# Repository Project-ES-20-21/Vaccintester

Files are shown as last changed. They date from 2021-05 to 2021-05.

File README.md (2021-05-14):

# RainbowSyringe
Dit is de uitleg horende bij de vaccintester uit de escape room.

## Inhoud

- [Algemene uitleg](#algemene-uitleg)
- [Flowcharts](#flowcharts)
- [Implementatie](#implementatie)
- [Budget](#budget)
- [Risico's](#risicos)
- [Gantt chart](#gantt-chart)

## Algemene uitleg

Door het oplossen van de 5G-puzzel, wordt er een RFID kaart verkregen. Die kaart kan gebruikt worden om de uiteindelijke kleurensequentie voor de vaccintester te vinden. In de deur van een kast zit op een bepaalde plaats een NFC reader. De spelers moeten dan met de kaart op zoek gaan naar de kast en uitzoeken waar in de deur de NFC reader zit. Door de kaart dan te scannen worden er witte leds in de kast geactiveerd. Boven elke witte led bevindt zich een gekleurde vloeistof in een proefbuis. De houders voor de proefbuis kunnen gebruikt worden om de witte leds weg te steken. De leds gaan in een bepaalde volgorde oplichten, zodat er een sequentie gevonden kan worden van 7 kleuren die na elkaar oplichten. Om die kleurensequentie in te geven wordt er gebruik gemaakt van drie knoppen die verspreid zijn in de ruimte. Bij elke knop hoort een kastje, hierin kan een voorwerp met een primaire kleur gestoken worden. Om de kleuren te vormen worden de knoppen dan ingedrukt, de kleur van het voorwerp wordt gescand. Om alle spelers te laten meedoen moeten de knoppen om de kleuren te vormen binnen een bepaald interval ingedrukt worden. Zo wordt geel gevormd door groen, rood en zwart moeten groen, rood en zwart dus ongeveer op hetzelfde moment ingedrukt worden. Die knoppen zorgen er dan voor dat de bijhorende ledstrip die zich in een spuit bevindt oplicht. Wanneer de juiste kleur verkregen is wordt er gesprongen naar de volgende kleur in de sequentie en herhaalt het vorige zich. Wanneer de laatste kleur juist is, wordt een random getal gegenereerd dat een digit van de te zoeken code is. Deze wordt doorgestuurd naar de centrale eenheid en ook getoond aan de deelnemers door het aantal proefbuizen die oplichten binnen de kast.

Om dit alles te kunnen uitvoeren wordt er gebruik gemaakt van twee ESP32's, die met elkaar kunnen communiceren via een ESPnow-connectie. Wanneer de juiste RFID gescand wordt, wordt er een signaal verzonden van de ESP32 die verbonden is met de NFC-reader naar de ESP32 die verbonden is met de kleursensoren, de drukknoppen en de leds binnen de spuit en in de kast. Dat signaal zal ervoor zorgen dat de kleursensoren, de leds binnen de spuit en in de kast en de drukknoppen geactiveerd worden.

Daarnaast zal de laatst besproken ESP via het wifi-netwerk geconnecteerd zijn met de broker. Op die manier kan er uiteindelijk een digit van de code die ingevoerd moet worden bij alohomara doorgestuurd worden naar de centrale eenheid of broker.

## Flowcharts
### Vaccintester
Flowchart_vaccintester
### RFID
Flowchart_RFID
### Buttons
Flowchart_buttons
### Centrale ESP32
Flowchart_centralESP32

## Implementatie

De positie van deze puzzel binnen het lokaal maakt in principe niet zo veel uit. Er moet wel voor gezorgd worden dat de knoppen minstens 1,5 meter van elkaar gescheiden zijn zodat telkens aan de voorwaarde van de "T'is beter op anderhalve meter"-puzzel voldaan is. Daarnaast gaat de spuit aan een muur moeten hangen zodat alles op een correcte manier aangesloten kan worden.

## Budget

| Artikel | Aantal | Kostprijs | Totaal  |
|---|---|---|---|
| Kleurensensor | 1 | 4.00 € | 4.00 €  |
| Esp32 | 2 | 5.79 € | 11.58 € |
| NRF24L01+ 2.4GHz wireless transceiver module | 3 | 1.95 € | 5.85 €  |
| Witte led | 7 | 0.42 € | 2.94 €  |
| Kleurenledstrip 1m | 1 | 10.00 € | 10.00 € |
| NFC reader | 1 | 5.00 € | 5.00 €  |
| Weerstanden | 7 | x | x |
| RobotDynUNO R3 | 1 | 11.00 € | 11.00 € |
| | | | |
| Hebben we reeds | | | 50.37 € |
| | | | |
| Drukknoppen | 3 | 2.00 € | 6.00 €  |
| Adapters | 5 | x | x |
| PCBway | 1 | 5.00 € | 5.00 €  |
| Kleurensensor | 2 | 4.00 € | 8.00 €  |
| RobotDynUNO R3 | 2 | 11.00 € | 22.00 € |
| | | | |
| Nog aan te kopen | | | 41.00 € |
| | | | |
| Totaal budget | | | 91.37 € |
| | | | |
## Risico's

- Wanneer de 5G-puzzle niet werkt, kan de nodige RFID kaart niet verkregen worden. Dit kan opgelost worden door een tweede kaart te gebruiken die ook gebruikt kan worden om onze puzzel te starten. Deze kaart kan ergens verstopt worden binnen de kamer. De positie van die kaart kan dan via een raadsel achterhaald worden.

- Wanneer de RFID reader en de receiver niet geconnecteerd zijn, kan de puzzel niet volledig gestart worden. Dit kan eventueel opgelost worden door Alohomora een signaal te laten versturen naar de tweede ESP32. 

- De kleursensor kan soms bij de eerste meting een fout resultaat geven. Dit kan opgelost worden door bijvoorbeeld tien metingen na elkaar te doen en het gemiddelde te nemen van de verschillende waarden.

- De kleursensor kan foute resultaten geven door reflectie. Er moet dus gebruik gemaakt worden van een buis die mat is, waardoor de resultaten geen invloed van reflectie zullen hebben.

## Gantt chart

Via volgende link gaat u naar onze Gantt chart horende bij dit project: 
[Gantt vaccintester (ClickUp)](https://share.clickup.com/g/h/4dne7-50/c3532202026c060)

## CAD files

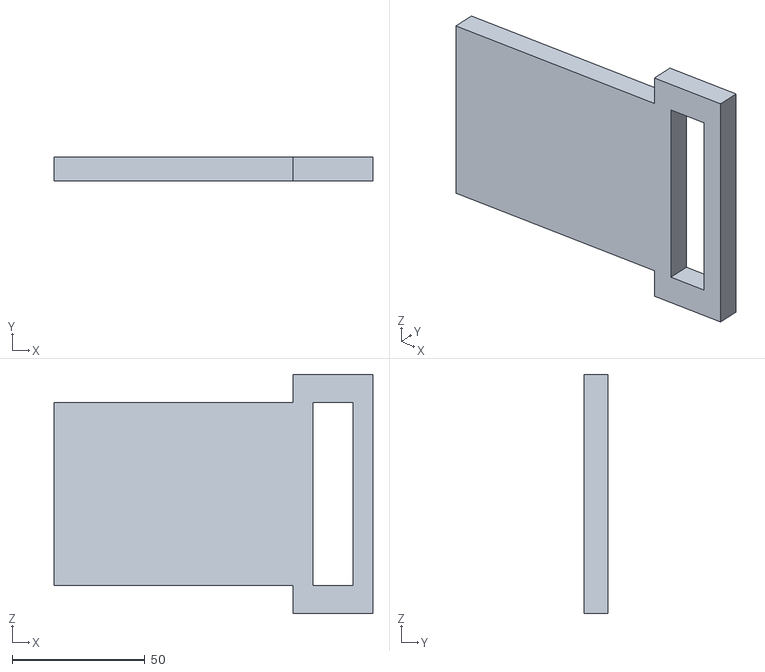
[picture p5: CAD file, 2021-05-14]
Kleur2.STL
120.0 x 9.00 x 90.0

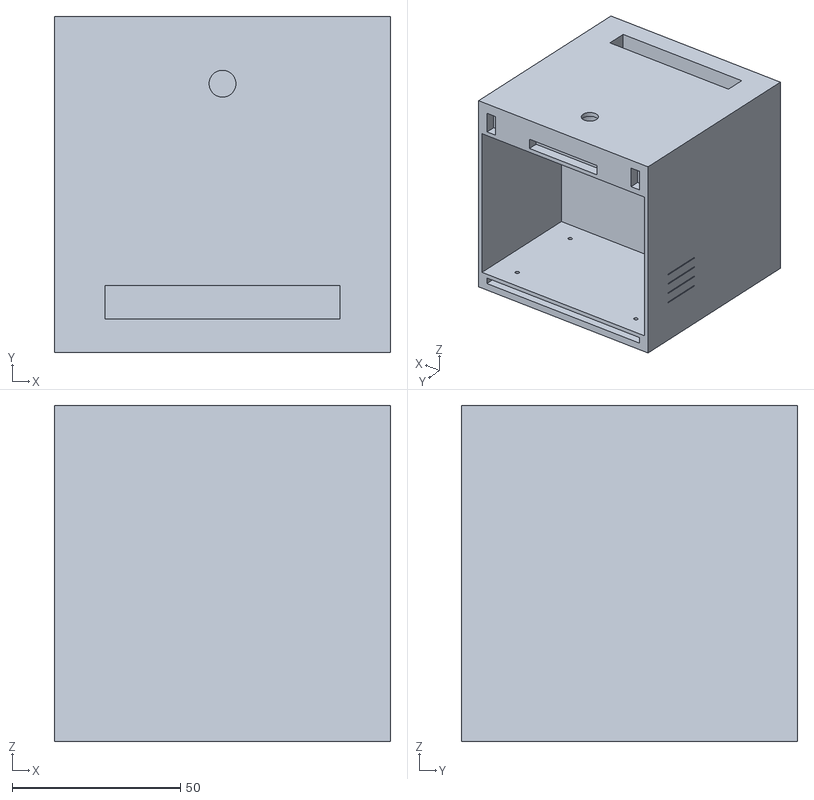
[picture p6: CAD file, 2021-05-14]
VaccintesterButtonF.STL
100.0 x 100.0 x 100.0

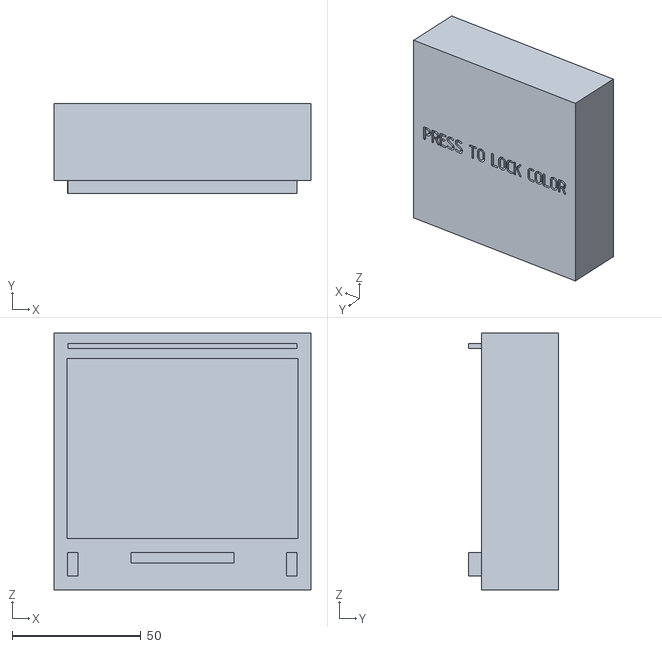
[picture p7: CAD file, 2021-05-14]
DekselButton.STL
100.0 x 35.0 x 100.0

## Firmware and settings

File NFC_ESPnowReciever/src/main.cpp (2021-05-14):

#include <Arduino.h>

#include <esp_now.h>
#include <WiFi.h>
#include "PubSubClient.h"
#include "Wire.h"
#include "SPI.h"
#include "Adafruit_SPIDevice.h"
#include "ESPAsyncWebServer.h"
#include <Arduino_JSON.h>
using namespace std;

#include <SPI.h>

//Mqtt constants
#define SSIDA "NETGEAR68"
#define PWD "excitedtuba713"
#define MQTT_SERVER "192.168.1.2" // could change if the setup is moved
#define MQTT_PORT 1883

WiFiClient espClient;
PubSubClient client(espClient);

unsigned long myPrevMillis;

void myDelay(int del)
{
  myPrevMillis = millis();
  while (millis() - myPrevMillis <= del)
  {
    client.loop();
  }
}

/////////////////////////////////////////////////////////////////////////////////////////////////////////////////////////////////////////
/////////////////////////////////////////////////////// SETUP LEDSTRIP //////////////////////////////////////////////////////////////////
/////////////////////////////////////////////////////////////////////////////////////////////////////////////////////////////////////////

#define red 26
#define green 27
#define blue 25

#define inPin 12

// setting PWM properties
const int freq = 5000;
const int redChannel = 0;
const int greenChannel = 1;
const int blueChannel = 2;
const int resolution = 8; //Resolution 8, 10, 12, 15

//=======================================================================
//                    Power on setup
//=======================================================================
void setupLed()
{

  pinMode(red, OUTPUT);
  pinMode(green, OUTPUT);
  pinMode(blue, OUTPUT);

  // configure LED PWM functionalitites
  ledcSetup(redChannel, freq, resolution);
  ledcSetup(greenChannel, freq, resolution);
  ledcSetup(blueChannel, freq, resolution);

  // attach the channel to the GPIO2 to be controlled
  ledcAttachPin(red, redChannel);
  ledcAttachPin(green, greenChannel);
  ledcAttachPin(blue, blueChannel);
}

void RGB_color(int red_light_value, int green_light_value, int blue_light_value)
{
  ledcWrite(redChannel, red_light_value);
  ledcWrite(greenChannel, green_light_value);
  ledcWrite(blueChannel, blue_light_value);
}

//int teller;
int redFrequency = 0;
int greenFrequency = 0;
int blueFrequency = 0;
int kleur = 6;

/*
  green = 0
  red = 1
  blue = 2
  yellow = 3
  purple = 4
  cyan = 5
  black = 6
*/

//Met behulp van de ontvangen kleuren de gemaakt kleur bepalen
int colorMaker(int mColor1, int mColor2)
{
  
  //groen
  if(((mColor1 == 0 || mColor2 == 0) && (mColor1 == 6 || mColor2 == 6)) || (mColor1 == 2 && mColor2 == 2)) {
      kleur=0;
      RGB_color(255, 0, 255);
    }
  //rood
  if(((mColor1 == 1 || mColor2 == 1) && (mColor1 ==6 || mColor2 ==6))|| (mColor1 == 1 && mColor2 == 1)) {
      kleur=1;
      RGB_color(0,255, 255);
    }
  //blauw
  if(((mColor1 == 2 || mColor2 == 2) && (mColor1 == 6 || mColor2 == 6)) || (mColor1 == 2 && mColor2 == 2)) {
      kleur=2;
      RGB_color(255, 255, 0);
    }
  //geel
  if((mColor1 == 0 || mColor2 == 0) && (mColor1 == 1 || mColor2 == 1)){
      kleur=3;
      RGB_color(0, 0, 255);
    }
  //paars
  if((mColor1 == 1|| mColor2 == 1) && (mColor1 == 2|| mColor2 == 2)){
      kleur=4;
      RGB_color(0, 255,0);
    }
  //cyaan
  if((mColor1 == 0|| mColor2 == 0) && (mColor1 == 2|| mColor2 == 2)){
      kleur=5;
      RGB_color(255, 0, 0);
    }
  if((mColor1 == 6)&&(mColor2 == 6)){
      kleur=6;
      RGB_color(0,0,0);
  }/*
  if (mColor1 == 0)
  {
    kleur = 0;
    RGB_color(255, 0, 255);
  }
  if (mColor1 == 1)
  {
    kleur = 1;
    RGB_color(0, 255, 255);
  }
  if (mColor1 == 2)
  {
    kleur = 2;
    RGB_color(255, 255, 0);
  }*/
  return kleur;
}

/////////////////////////////////////////////////////////////////////////////////////////////////////////////////////////////////////////
//////////////////////////////////////////////////////////// SETUP MQTT /////////////////////////////////////////////////////////////////
/////////////////////////////////////////////////////////////////////////////////////////////////////////////////////////////////////////

int sequence[7];

int reset = 0;
int pauze = 0;
int digitCode;
int color1;
int color2;
String sequentiestring;

void callback(char *topic, byte *message, unsigned int length);

void setup_wifi()
{
  myDelay(10);
  Serial.println("Connecting to WiFi..");

  WiFi.begin(SSIDA, PWD);

  while (WiFi.status() != WL_CONNECTED)
  {
    myDelay(500);
    Serial.print(".");
  }

  Serial.println("");
  Serial.println("WiFi connected");
  Serial.println("IP address: ");
  Serial.println(WiFi.localIP());
}

int pauzeFitness=0;
int pauzeOntsmet=0;

void callback(char *topic, byte *message, unsigned int length)
{
  Serial.print("Message arrived on topic: ");
  Serial.print(topic);
  Serial.print(". Message: ");
  String messageTemp;

  for (int i = 0; i < length; i++)
  {
    Serial.print((char)message[i]);
    messageTemp += (char)message[i];
  }
  Serial.println();

  // Feel free to add more if statements to control more GPIOs with MQTT

  // If a message is received on the topic esp32/output, you check if the message is either "on" or "off".
  // Changes the output state according to the message
  if (String(topic) == "esp32/vaccin/control")
  {
    //0 -- Reset
    if (messageTemp == "0")
    {
      for (int i = 0; i < 10; i++)
    {
      RGB_color(0, 255, 0);
      myDelay(200);
      RGB_color(255, 255, 255);
      myDelay(200);
    }
      ESP.restart();
      //reset = true;
    }
    //1 -- Pause ontsmetting
    if (messageTemp == "1")
    {
      pauzeOntsmet=1;
    }
    //2 -- Continue ontsmetting
    if (messageTemp == "2")
    {
      pauzeOntsmet=0;
    }
    //3 -- Pause fitness
    if (messageTemp == "3")
    {
      pauzeFitness=1;
    }
    //4 -- Continue ontsmetting
    if (messageTemp == "4")
    {
      pauzeOntsmet=0;
    }
  }

  if (String(topic) == "esp32/vaccin/button1")
  {
    Serial.println("Button1");
    color1 = messageTemp.toInt();
  }

  if (String(topic) == "esp32/vaccin/button2")
  {
    Serial.println("Button2");
    color2 = messageTemp.toInt();
  }

  if (String(topic) == "esp32/vaccin/kast")
  {
    Serial.println("Kast");
    sequentiestring = messageTemp;
    Serial.println(sequentiestring);
    sequence[0] = sequentiestring.substring(0, 1).toInt();
    sequence[1] = sequentiestring.substring(1, 2).toInt();
    sequence[2] = sequentiestring.substring(2, 3).toInt();
    sequence[3] = sequentiestring.substring(3, 4).toInt();
    sequence[4] = sequentiestring.substring(4, 5).toInt();
    sequence[5] = sequentiestring.substring(5, 6).toInt();
    sequence[6] = sequentiestring.substring(6, 7).toInt();

    for (int i = 0; i < 7; i++)
    {
      Serial.println(sequence[i]);
    }
  }
  if (String(topic) == "esp32/vaccin/number")
  {
    Serial.println(messageTemp);
  }
}

// function to establish MQTT connection
void reconnect()
{
  myDelay(10);
  // Loop until we're reconnected
  while (!client.connected())
  {
    Serial.print("Attempting MQTT connection...");
    // Attempt to connect
    if (client.connect("ESP32vaccin"))
    {
      Serial.println("connected");

      // ... and resubscribe
      client.subscribe("esp32/vaccin/control");
      client.subscribe("esp32/vaccin/number");
      client.subscribe("esp32/vaccin/button1");
      client.subscribe("esp32/vaccin/button2");
      client.subscribe("esp32/vaccin/kast");
    }
    else
    {
      Serial.print("failed, rc=");
      Serial.print(client.state());
      Serial.println(" try again in 5 seconds");
      myDelay(5000);
    }
  }
}

/////////////////////////////////////////////////////////////////////////////////////////////////////////////////////////////////////////
//////////////////////////////////////////////////////////// SETUP //////////////////////////////////////////////////////////////////////
/////////////////////////////////////////////////////////////////////////////////////////////////////////////////////////////////////////

void setup()
{
  //Initialize Serial Monitor
  Serial.begin(115200);

  setup_wifi();
  client.setServer(MQTT_SERVER, MQTT_PORT);
  client.setCallback(callback);

  //Set device as a Wi-Fi Station
  WiFi.mode(WIFI_STA);

  setupLed();
}

int val = 0;
int mixedColor;
int correct = 0;
int check = 0;

/////////////////////////////////////////////////////////////////////////////////////////////////////////////////////////////////////////
//////////////////////////////////////////////////////////// LOOP  //////////////////////////////////////////////////////////////////////
/////////////////////////////////////////////////////////////////////////////////////////////////////////////////////////////////////////

void loop()
{
  if (!client.connected())
  {
    reconnect();
  }
  client.loop();

  val = digitalRead(inPin); // read input value
  if ((val == HIGH) && (correct < 7) && (pauzeOntsmet == 0) && (pauzeFitness==0))
  {
    Serial.println("push");
    kleur = colorMaker(color2, color1);
    myDelay(1000);
    if (kleur != sequence[correct])
    {
      correct = 0;
      Serial.println(sequence[correct]);
      Serial.println("fout");
      for (int i = 0; i < 3; i++)
      {
        RGB_color(0, 255, 255); //rood laten pinken
        myDelay(350);
        RGB_color(255, 255, 255);
        myDelay(350);
      }
      colorMaker(color2, color1);
    }

    else if (kleur == sequence[correct])
    {
      Serial.println("Juist");
      correct++;
      Serial.println(sequence[correct]);
      for (int i = 0; i < 3; i++)
      {
        RGB_color(255, 0, 255); //groen laten pinken
        myDelay(350);
        RGB_color(255, 255, 255);
        myDelay(350);
      }
      colorMaker(color2, color1);
    }
  }

  if ((correct == 7) && (check == 0))
  {
    //random getal aanmaken
    srand(time(NULL));
    digitCode = rand() % 10;
    Serial.println(digitCode);

    String number = (String)digitCode;
    const char *alohomora = number.c_str();
    client.publish("esp32/vaccin/number", alohomora);
    Serial.println("Alohomora sent");

    //dat getal sturen naar de centrale
    //tonen op de ledstrip door aantal keer te laten pinken in wit
    for (int j = 0; j < 15; j++)
    { //15 keer het juiste getal laten zien afgewisseld met rood pinken
      for (int i = 0; i < digitCode; i++)
      {
        RGB_color(0, 0, 0);
        myDelay(350);
        RGB_color(255, 255, 255);
        myDelay(350);
      }
      for (int i = 0; i < digitCode; i++)
      {
        RGB_color(255, 255, 0);
        myDelay(350);
        RGB_color(255, 255, 255);
        myDelay(350);
      }
    }
    check = 1;
  }
}

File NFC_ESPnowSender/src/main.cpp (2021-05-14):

#include <Arduino.h>
#include <Wire.h>
#include <SPI.h>
#include <Adafruit_PN532.h>

#include <esp_now.h>
#include <esp_wifi.h>
#include <WiFi.h>
#include <Adafruit_Sensor.h>
#include <DHT.h>

#include <bits/stdc++.h>
#include <vector>
#include <algorithm>

using namespace std;

#include "PubSubClient.h"
#include "Wire.h"
#include "SPI.h"

//Mqtt constants
#define SSIDA "NETGEAR68"
#define PWD "excitedtuba713"
#define MQTT_SERVER "192.168.1.2" // could change if the setup is moved
#define MQTT_PORT 1883

WiFiClient espClient;
PubSubClient client(espClient);

unsigned long myPrevMillis;

void myDelay(int del)
{
  myPrevMillis = millis();
  while (millis() - myPrevMillis <= del)
  {
    client.loop();
  }
}

/////////////////////////////////////////////////////////////////////////////////////////////////////////////////////////////////////////
///////////////////////////////////////////////////////// SETUP NFC /////////////////////////////////////////////////////////////////////
/////////////////////////////////////////////////////////////////////////////////////////////////////////////////////////////////////////

static void startListeningToNFC();
static String handleCardDetected();

// Pins used for I2C IRQ
#define PN532_IRQ 4
#define PN532_RESET 5

//Pinnen leds
int red_color = 25;
int blue_color = 26;
int green_color = 27;
int yellow_color = 32;
int purple_color = 33;
int cyan_color = 14;

void setupPins()
{
  //Setup voor aansturen leds
  pinMode(blue_color, OUTPUT);
  pinMode(red_color, OUTPUT);
  pinMode(green_color, OUTPUT);
  pinMode(cyan_color, OUTPUT);
  pinMode(purple_color, OUTPUT);
  pinMode(yellow_color, OUTPUT);
}

const int DELAY_BETWEEN_CARDS = 500;
long timeLastCardRead = 0;
boolean readerDisabled = false;
int irqCurr;
int irqPrev;

//black Peter
string valid_tags = "0X04 0X9C 0X6E 0X6A 0X99 0X5B 0X80";

string reset_tags = "0X83 0X63 0XB3 0X03 0X00 0X00 0X00";

String hexToString(uint8_t *cardid);
boolean control(string kaart);

// This example uses the IRQ line, which is available when in I2C mode.
Adafruit_PN532 nfc(PN532_IRQ, PN532_RESET);

void startListeningToNFC()
{
  // Reset our IRQ indicators
  irqPrev = irqCurr = HIGH;

  Serial.println("Present an ISO14443A Card ...");
  nfc.startPassiveTargetIDDetection(PN532_MIFARE_ISO14443A);
}

String handleCardDetected()
{
  uint8_t success = false;
  uint8_t uid[] = {0, 0, 0, 0, 0, 0, 0}; // Buffer to store the returned UID
  uint8_t uidLength;                     // Length of the UID (4 or 7 bytes depending on ISO14443A card type)

  // read the NFC tag's info
  success = nfc.readDetectedPassiveTargetID(uid, &uidLength);
  Serial.println(success ? "Read successful" : "Read failed (not a card?)");

  if (success)
  {
    timeLastCardRead = millis();
  }

  // The reader will be enabled again after DELAY_BETWEEN_CARDS ms will pass.
  readerDisabled = true;
  return hexToString(uid);
}

String hexToString(uint8_t *cardid)
{

  int length = 7; //zonder +3 worden slechts 4 bytes genomen -> moet opgelost worden
  stringstream ss;
  for (int i = 0; i < length - 1; i++)
  {
    ss << "0x";
    if ((int)cardid[i] <= 15)
    {
      ss << "0";
    }
    ss << hex << (int)cardid[i];
    ss << " ";
  }
  ss << "0x";
  if ((int)cardid[length - 1] <= 15)
  {
    ss << "0";
  }
  ss << hex << (int)cardid[length - 1];
  string mystrC = ss.str();
  String mystr = mystrC.c_str();
  mystr.toUpperCase();
  Serial.println(mystr.c_str());
  return mystr;
}

/////////////////////////////////////////////////////////////////////////////////////////////////////////////////////////////////////////
//////////////////////////////////////////////////////// MQTT ///////////////////////////////////////////////////////////////////////////
/////////////////////////////////////////////////////////////////////////////////////////////////////////////////////////////////////////

int send;
int measColor;
String number;
int card = 0;
int volgorde[7];

void callback(char *topic, byte *message, unsigned int length);

void setup_wifi()
{
  myDelay(10);
  Serial.println("Connecting to WiFi..");

  WiFi.begin(SSIDA, PWD);

  while (WiFi.status() != WL_CONNECTED)
  {
    myDelay(500);
    Serial.print(".");
  }

  Serial.println("");
  Serial.println("WiFi connected");
  Serial.println("IP address: ");
  Serial.println(WiFi.localIP());
}

void ledOff()
{
  digitalWrite(green_color, LOW);
  digitalWrite(yellow_color, LOW);
  digitalWrite(red_color, LOW);
  digitalWrite(purple_color, LOW);
  digitalWrite(blue_color, LOW);
  digitalWrite(cyan_color, LOW);
}
void nullSequence()
{
  for (int i = 0; i < 7; i++)
  {
    volgorde[i] = 7;
  }
}

void Ledup(int nrLed, int delay0ff, int delayOn)
{
  digitalWrite(nrLed, HIGH);
  myDelay(1500);
  digitalWrite(nrLed, LOW);
  myDelay(300);
}

void ledReset(){
  Ledup(green_color,50,0);
  Ledup(red_color,50,0);
  Ledup(blue_color,50,0);
  Ledup(yellow_color,50,0);
  Ledup(purple_color,50,0);
  Ledup(cyan_color,50,0);
  Ledup(cyan_color,50,0);
  Ledup(purple_color,50,0);
  Ledup(yellow_color,50,0);
  Ledup(blue_color,50,0);
  Ledup(red_color,50,0);
  Ledup(green_color,50,0);
}

void callback(char *topic, byte *message, unsigned int length)
{
  Serial.print("Message arrived on topic: ");
  Serial.print(topic);
  Serial.print(". Message: ");
  Serial.println();
  String messageTemp;

  for (int i = 0; i < length; i++)
  {
    Serial.print((char)message[i]);
    messageTemp += (char)message[i];
  }
  Serial.println();

  if (String(topic) == "esp32/vaccin/control")
  {
    if (messageTemp == "0")
    {
      Serial.println("Reset");      
      ledReset();
      card=0;
      ESP.restart();
    }
  }
}

// function to establish MQTT connection
void reconnect()
{
  myDelay(10);
  // Loop until we're reconnected
  while (!client.connected())
  {
    Serial.print("Attempting MQTT connection...");
    // Attempt to connect
    if (client.connect("ESP32vaccinkast"))
    {
      Serial.println("connected");

      // ... and resubscribe
      client.subscribe("esp32/vaccin/control");
      client.subscribe("esp32/vaccin/number");
      client.subscribe("esp32/vaccin/button1");
      client.subscribe("esp32/vaccin/button2");
      client.subscribe("esp32/vaccin/kast");
    }
    else
    {
      Serial.print("failed, rc=");
      Serial.print(client.state());
      Serial.println(" try again in 5 seconds");
      myDelay(5000);
    }
  }
}

/////////////////////////////////////////////////////////////////////////////////////////////////////////////////////////////////////////
/////////////////////////////////////////////////////// SETUP ///////////////////////////////////////////////////////////////////////////
/////////////////////////////////////////////////////////////////////////////////////////////////////////////////////////////////////////
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
